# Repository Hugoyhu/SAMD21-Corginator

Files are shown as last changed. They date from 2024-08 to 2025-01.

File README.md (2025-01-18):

# SAMD21-Corginator

The Corginator _v2_ is an updated version of the original Corginator (which had an ATMEGA328P microcontroller). Here's what's new:
* ATMega328P replaced with ATSAMD21G18 (faster, more memory, more storage, and more bits!)
* ICSP programming replaced with keyed SWD header 
* Bulky USB Type-B replaced with USB Type-C connector
* Arduino Nano form factor replaced with Adafruit Feather form factor
* Li-poly single cell battery charging enabled with Microchip MCP73831
* Smaller and lighter design

___CHECK BATTERY PINOUT FIRST. POLARITY MAY BE REVERSED.___
# Open Source Hardware

The Corginator v2 is open source hardware. This design was created in [KiCAD](https://www.kicad.org), an FOSS schematic capture and PCB layout / routing software. While schematics are provided in PDF format, you will need the latest version of KiCAD (v8 or above) to directly view and modify the schematic and PCB. 

## Schematic
PNG of Schematic Capture

## PCB 
Image of Assembled Corginator

# Attribution 

This design uses the [Adafruit Feather M0](https://www.adafruit.com/product/2772) as a reference design for both the SAMD21 and battery charging. I also used their [wonderful tutorial](https://learn.adafruit.com/how-to-program-samd-bootloaders/overview) to flash a bootloader onto the Corginator with my Segger J-link EDU. 

To support Adafruit's open-source hardware _and_ software development, please consider using their USA-designed & manufacturered products in your next project.

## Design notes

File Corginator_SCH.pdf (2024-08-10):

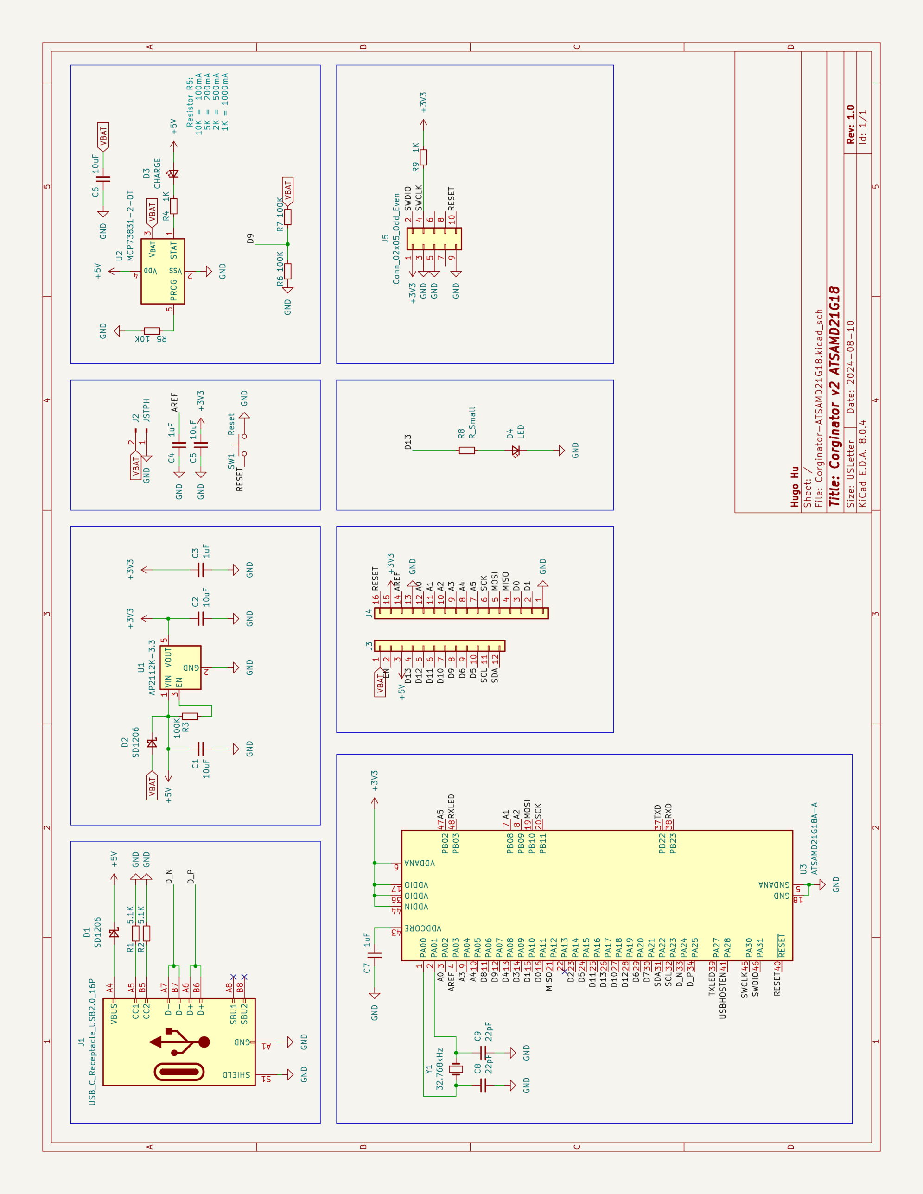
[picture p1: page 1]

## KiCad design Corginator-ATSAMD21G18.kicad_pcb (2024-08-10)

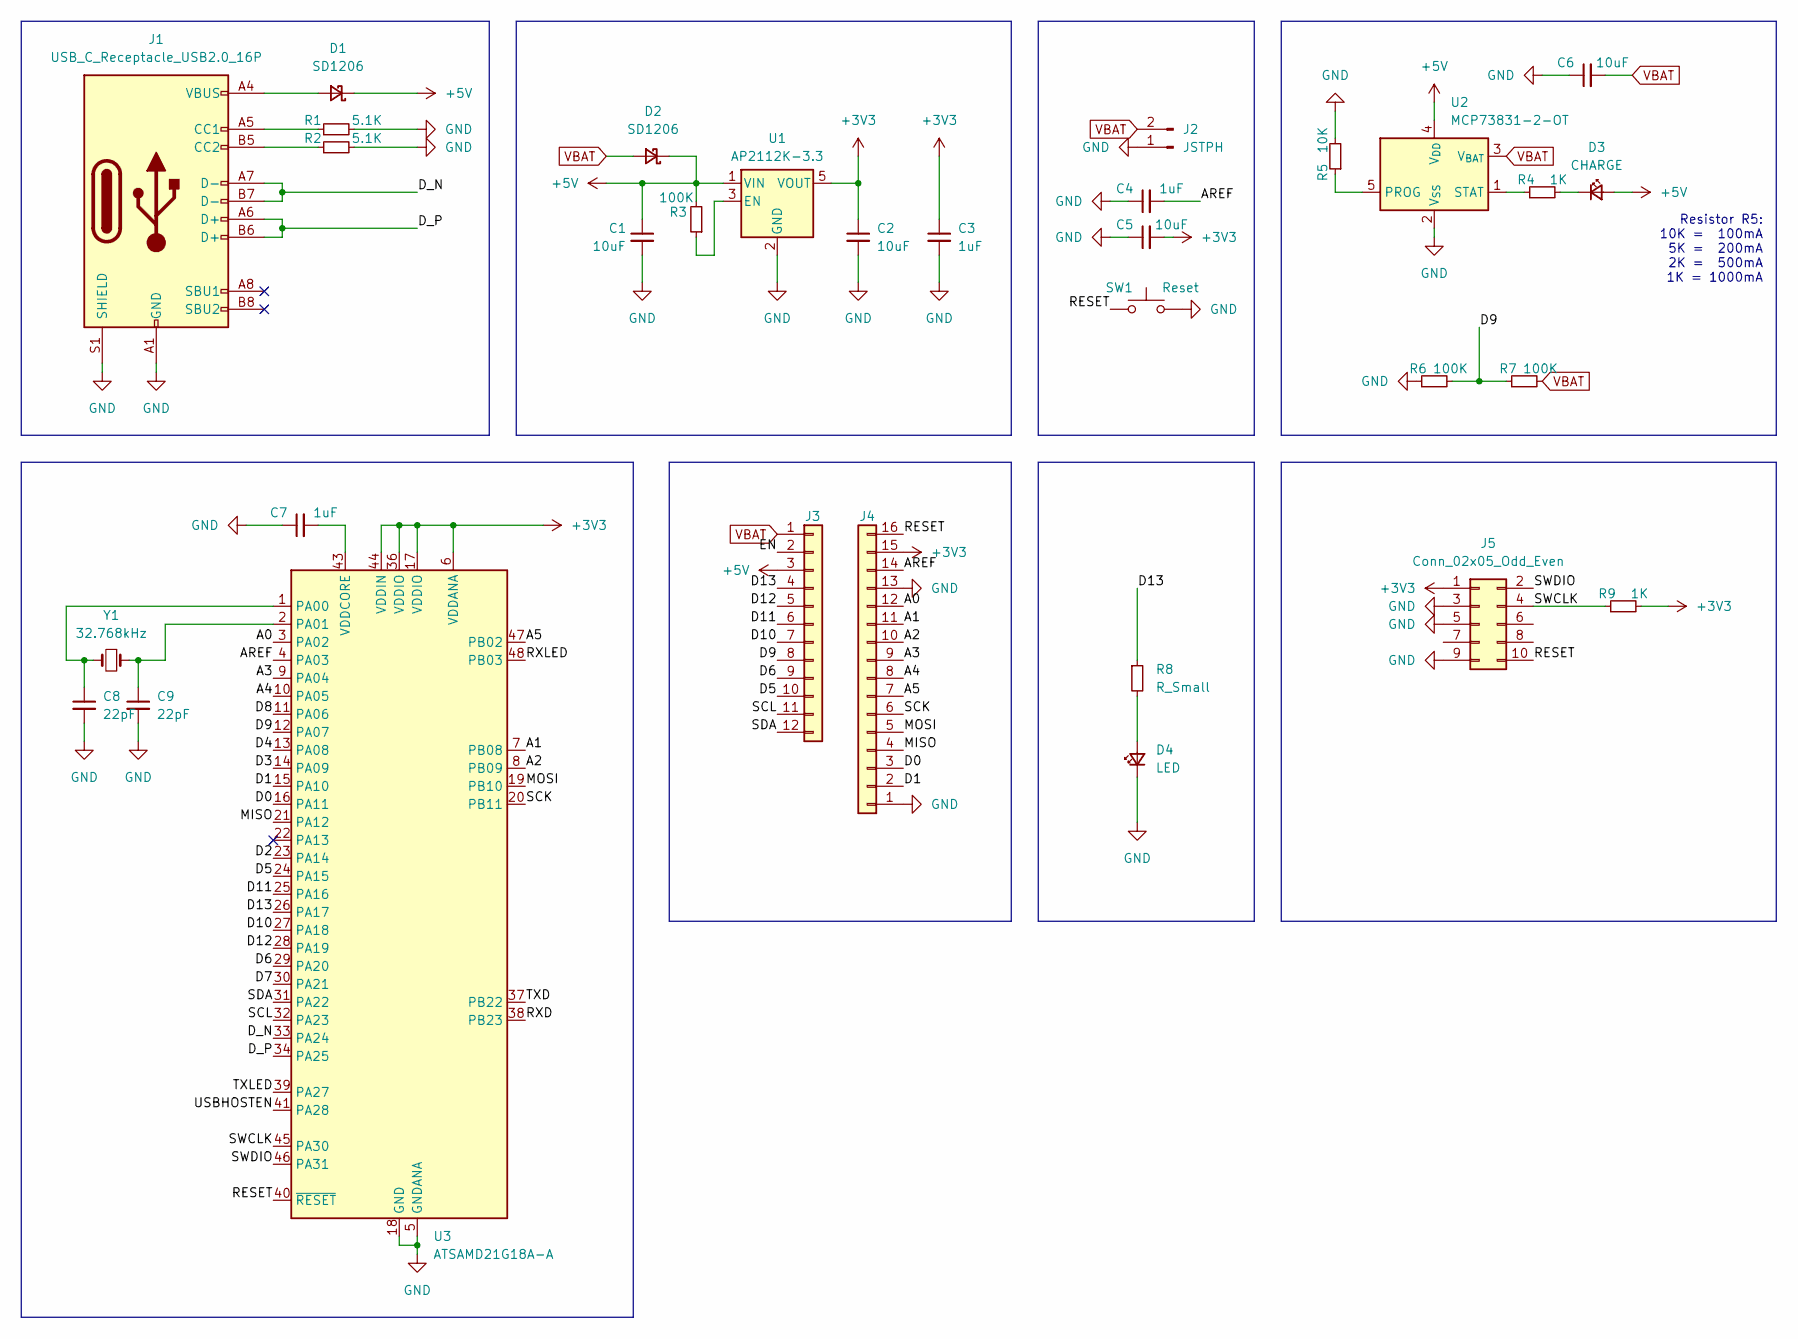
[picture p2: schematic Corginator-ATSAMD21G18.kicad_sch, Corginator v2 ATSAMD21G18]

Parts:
C1, C2, C5, C6: 10uF; C_0603_1608Metric_Pad1.08x0.95mm_HandSolder
C3, C4, C7: 1uF; C_0603_1608Metric_Pad1.08x0.95mm_HandSolder
C8, C9: 22pF; C_0603_1608Metric_Pad1.08x0.95mm_HandSolder
D1, D2: SD1206; D_1206_3216Metric_Pad1.42x1.75mm_HandSolder
D3: CHARGE; LED_0603_1608Metric_Pad1.05x0.95mm_HandSolder
D4: LED; LED_0805_2012Metric_Pad1.15x1.40mm_HandSolder
J1: USB_C_Receptacle_USB2.0_16P; USB_C_Receptacle_HRO_TYPE-C-31-M-12
J2: JSTPH; JST_PH_B2B-PH-SM4-TB_1x02-1MP_P2.00mm_Vertical
J3: Conn_01x12; PinSocket_1x12_P2.54mm_Vertical
J4: Conn_01x16; PinSocket_1x16_P2.54mm_Vertical
J5: Conn_02x05_Odd_Even; PinHeader_2x05_P1.27mm_Vertical
R1, R2: 5.1K; R_0603_1608Metric_Pad0.98x0.95mm_HandSolder
R3, R6, R7: 100K; R_0603_1608Metric_Pad0.98x0.95mm_HandSolder
R4, R9: 1K; R_0603_1608Metric_Pad0.98x0.95mm_HandSolder
R5: 10K; R_0603_1608Metric_Pad0.98x0.95mm_HandSolder
R8: R_Small; R_0603_1608Metric_Pad0.98x0.95mm_HandSolder
SW1: Reset; SW_SPST_PTS645
U1: AP2112K-3.3; SOT-23-5
U2: MCP73831-2-OT; SOT-23-5
U3: ATSAMD21G18A-A; TQFP-48_7x7mm_P0.5mm
Y1: 32.768kHz; Crystal_Round_D3.0mm_Vertical

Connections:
+3V3: C2.1, C3.1, C5.2, J4.15, J5.1, R9.2, U1.5 (VOUT), U3.6 (VDDANA), U3.17 (VDDIO), U3.36 (VDDIO), U3.44 (VDDIN)
+5V: C1.1, D1.1 (K), D2.1 (K), D3.2 (A), J3.3, R3.2, U1.1 (VIN), U2.4 (V_{DD})
/A0: J4.12, U3.3 (PA02)
/A1: J4.11, U3.7 (PB08)
/A2: J4.10, U3.8 (PB09)
/A3: J4.9, U3.9 (PA04)
/A4: J4.8, U3.10 (PA05)
/A5: J4.7, U3.47 (PB02)
/AREF: C4.2, J4.14, U3.4 (PA03)
/D0: J4.3, U3.16 (PA11)
/D1: J4.2, U3.15 (PA10)
/D2: U3.23 (PA14)
/D3: U3.14 (PA09)
/D4: U3.13 (PA08)
/D5: J3.10, U3.24 (PA15)
/D6: J3.9, U3.29 (PA20)
/D7: U3.30 (PA21)
/D8: U3.11 (PA06)
/D9: J3.8, R6.2, R7.1, U3.12 (PA07)
/D10: J3.7, U3.27 (PA18)
/D11: J3.6, U3.25 (PA16)
/D12: J3.5, U3.28 (PA19)
/D13: J3.4, R8.1, U3.26 (PA17)
/D_N: J1.A7 (D-), J1.B7 (D-), U3.33 (PA24)
/D_P: J1.A6 (D+), J1.B6 (D+), U3.34 (PA25)
/EN: J3.2
/MISO: J4.4, U3.21 (PA12)
/MOSI: J4.5, U3.19 (PB10)
/RESET: J4.16, J5.10, SW1.1, U3.40 (~RESET)
/RXD: U3.38 (PB23)
/RXLED: U3.48 (PB03)
/SCK: J4.6, U3.20 (PB11)
/SCL: J3.11, U3.32 (PA23)
/SDA: J3.12, U3.31 (PA22)
/SWCLK: J5.4, R9.1, U3.45 (PA30)
/SWDIO: J5.2, U3.46 (PA31)
/TXD: U3.37 (PB22)
/TXLED: U3.39 (PA27)
/USBHOSTEN: U3.41 (PA28)
GND: C1.2, C2.2, C3.2, C4.1, C5.1, C6.1, C7.1, C8.2, C9.2, D4.1 (K), J1.A1 (GND), J1.A12 (GND), J1.B1 (GND), J1.B12 (GND), J1.S1 (SHIELD), J2.1, J4.1, J4.13, J5.3, J5.5, J5.9, R1.2, R2.2, R5.2, R6.1, SW1.2, U1.2 (GND), U2.2 (V_{SS}), U3.5 (GNDANA), U3.18 (GND), U3.35 (GND), U3.42 (GND)
unnamed: D1.2 (A), J1.A4 (VBUS), J1.A9 (VBUS), J1.B4 (VBUS), J1.B9 (VBUS)
unnamed: D3.1 (K), R4.2
unnamed: D4.2 (A), R8.2
unnamed: J1.A5 (CC1), R1.1
unnamed: J1.B5 (CC2), R2.1
unnamed: R3.1, U1.3 (EN)
unnamed: R5.1, U2.5 (PROG)
unnamed: R4.1, U2.1 (STAT)
unnamed: C8.1, U3.1 (PA00), Y1.2
unnamed: C9.1, U3.2 (PA01), Y1.1
unnamed: C7.2, U3.43 (VDDCORE)
VBAT: C6.2, D2.2 (A), J2.2, J3.1, R7.2, U2.3 (V_{BAT})

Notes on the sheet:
Resistor R5: 10K = 100mA 5K = 200mA 2K = 500mA 1K = 1000mA

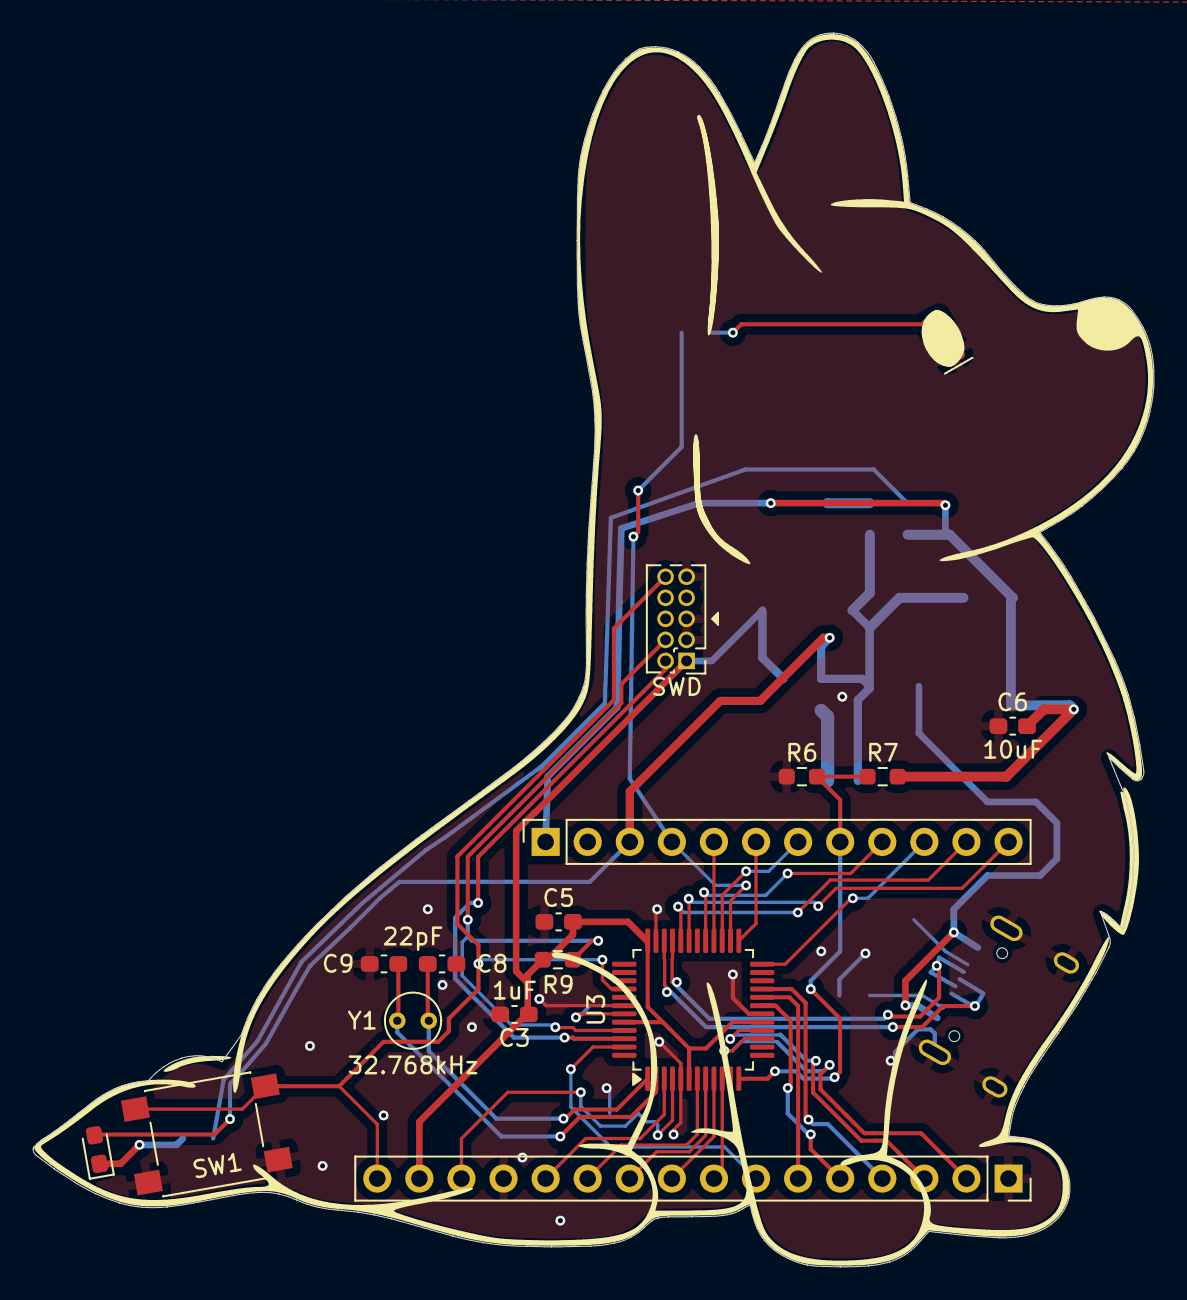
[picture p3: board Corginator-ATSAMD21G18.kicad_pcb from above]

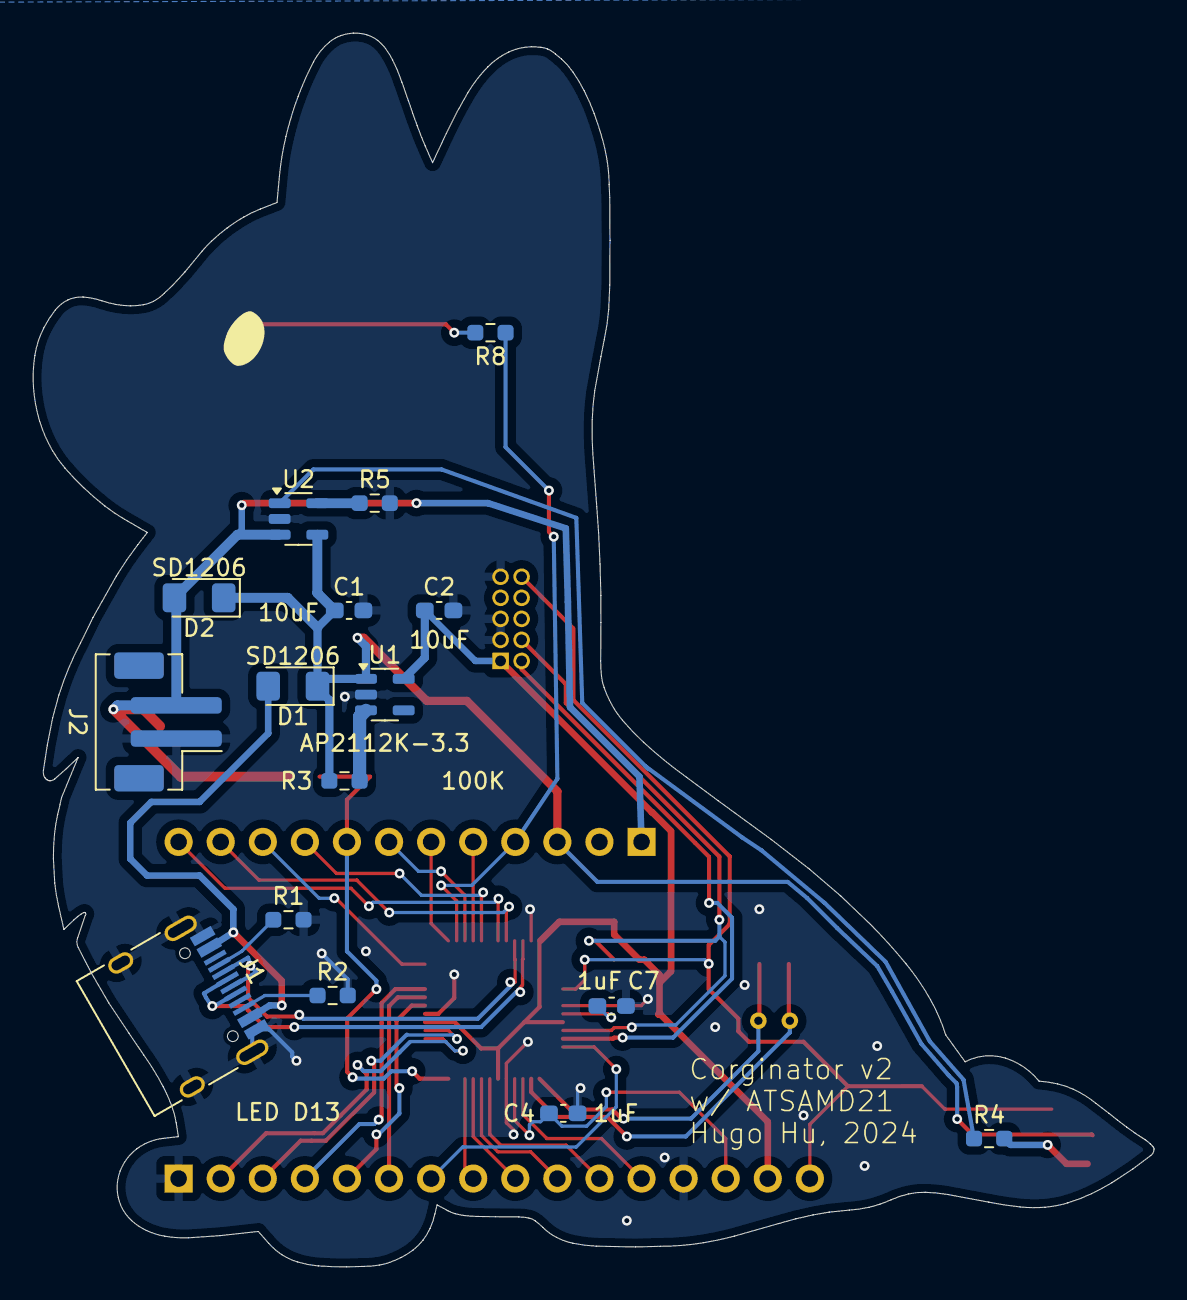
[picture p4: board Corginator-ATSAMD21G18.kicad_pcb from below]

Board: 2 copper layers, 67.7 x 74.5 mm, 32 parts (16 on the bottom side), 41 nets.

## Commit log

2024-08-10 add kicad files
    [Corginator-ATSAMD21G18.kicad_pcb, Corginator-ATSAMD21G18.kicad_sch]
2024-08-10 Add files via upload
    update for consistency
    [Corginator-ATSAMD21G18.kicad_pcb, Corginator-ATSAMD21G18.kicad_sch]
